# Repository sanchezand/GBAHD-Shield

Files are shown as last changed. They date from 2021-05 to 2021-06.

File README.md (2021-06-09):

# gbaHD Shield
This is a shield for the [gbaHD project](https://github.com/zwenergy/gbaHD).  

Has the following features.
- Connects via female headers to the Edge board (shield)
- Has a FFC 40, 32 and 34 pin connector for GBA LCD connector.
- Has a FFC 20 pin connector for controls with a wire up board.
- Has a ATMEGA328p for using a SNES Classic connector to control the GBA.
- **Both FFC cables need to be opposite side**

## Issues
- Havent had the chance to fully test the controller extension board, but the controller port on it works.
- Controller extension board needs to be made bigger and separate the button from the LED and the LED from the controller port.
- No case made for it yet
- GND pin on the breakout board needs to be moved (doesnt affect anything)
- Labels on breakout board need to be made bigger

## Contributing
If you wish to contribute, see something wrong or want to add a feature please make a pull request or leave an issue!

## BOM
|Reference	|Value								|
|---	|---							|
|C1, C2		|22pF									|
|C3			|100nF								|
|R1			|10K ohm									|
|R2			|120 ohm (or change for your LED)	|
|D1			|5mm LED or<br />TJ-L5FPTGCRMFCSFLC2R-A5	|
|U2			|ATMEGA328p-AU						|
|X1			|16MHz Crystal SMD-3225			|
|SW1			|XKB-TS-1185EC-C-D-B				|
|SW2			|XKB_XKB5858-Z-C					|
|J1			|JUSHUO_AFC01-S40FCC-00			|
|J2			|PinHeader 2x08 2.54mm			|
|J3, J9		|JUSHUO_AFC01-S20FCC-00			|
|J5			|JUSHUO_AFC07-S34FCC-00			|
|J7			|JUSHUO_AFC01-S32FCC-00			|
|J4			|PinHeader 2x10 2.54mm			|
|P1, P2		|Wii Expansion Port				|
|EXTRA 1		|PinHeader 1x08 2.54mm			|
|EXTRA 2		|PinHeader 1x06 2.54mm			|

## Programming the MCU
In order to program the MCU, you need an arduino to use as ISP.  
Use the following image to wire up an arduino to the board to program it.  
**I would also recomend not programming it while seated in the FPGA board.**
PCB Wireup  
After wiring the board, follow this tutorial to flash the bootloader and the sketch to the board.  
[ICSP Tutorial](https://www.arduino.cc/en/pmwiki.php?n=Tutorial/ArduinoISP)  
  
The Arduino code requires the [NintendoExtensionCtrl](https://github.com/dmadison/NintendoExtensionCtrl) library.

## Version 1 vs Version 2
- __Removed SNES connector for an classic controller connector__
- Made the PCB bigger and uses lower pins to improve stability
- Added future proof pins to the edge board.
- Panelized the board to lower the amount of PCBs needed
- Added an "Expansion" board to relocate the controller port and add an LED and power switch (which needs to desolder old switch and be wired to the Spartan board)
- Made the breakout board bigger and added more extra pins.
- Changed FFC connectors (except 34 pin) to use a clamp down connector.

## Images
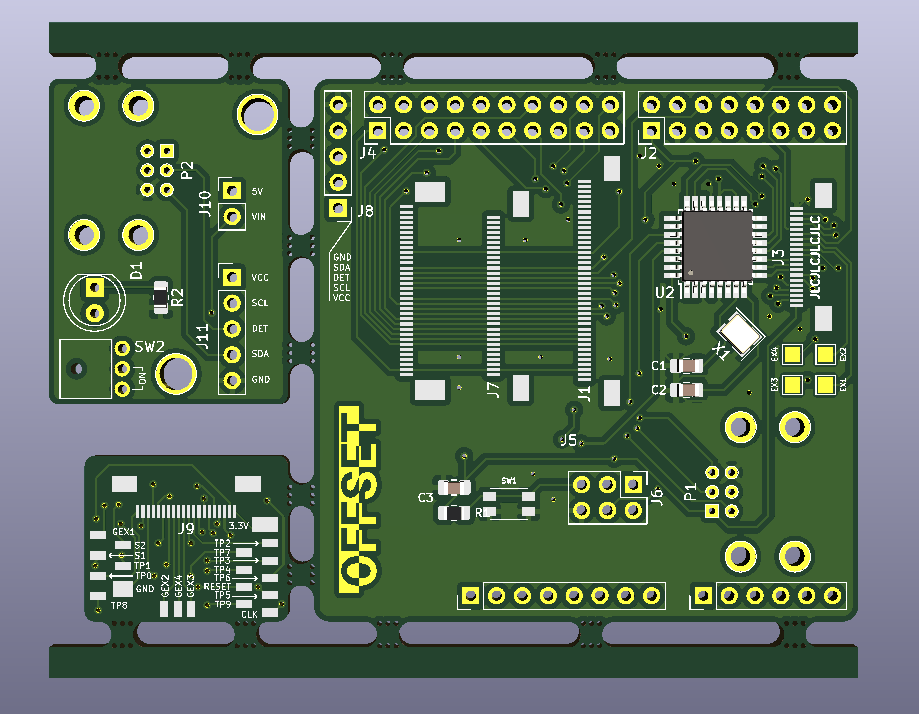
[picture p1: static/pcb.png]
PCB


## LICENSE
This documentation describes Open Hardware and is licensed under the CERN OHL v. 1.2.
You may redistribute and modify this documentation under the terms of the CERN OHL v.1.2. (http://ohwr.org/cernohl). This documentation is distributed WITHOUT ANY EXPRESS OR IMPLIED WARRANTY, INCLUDING OF MERCHANTABILITY, SATISFACTORY QUALITY AND FITNESS FOR A PARTICULAR PURPOSE. Please see the CERN OHL v.1.2 for applicable conditions.

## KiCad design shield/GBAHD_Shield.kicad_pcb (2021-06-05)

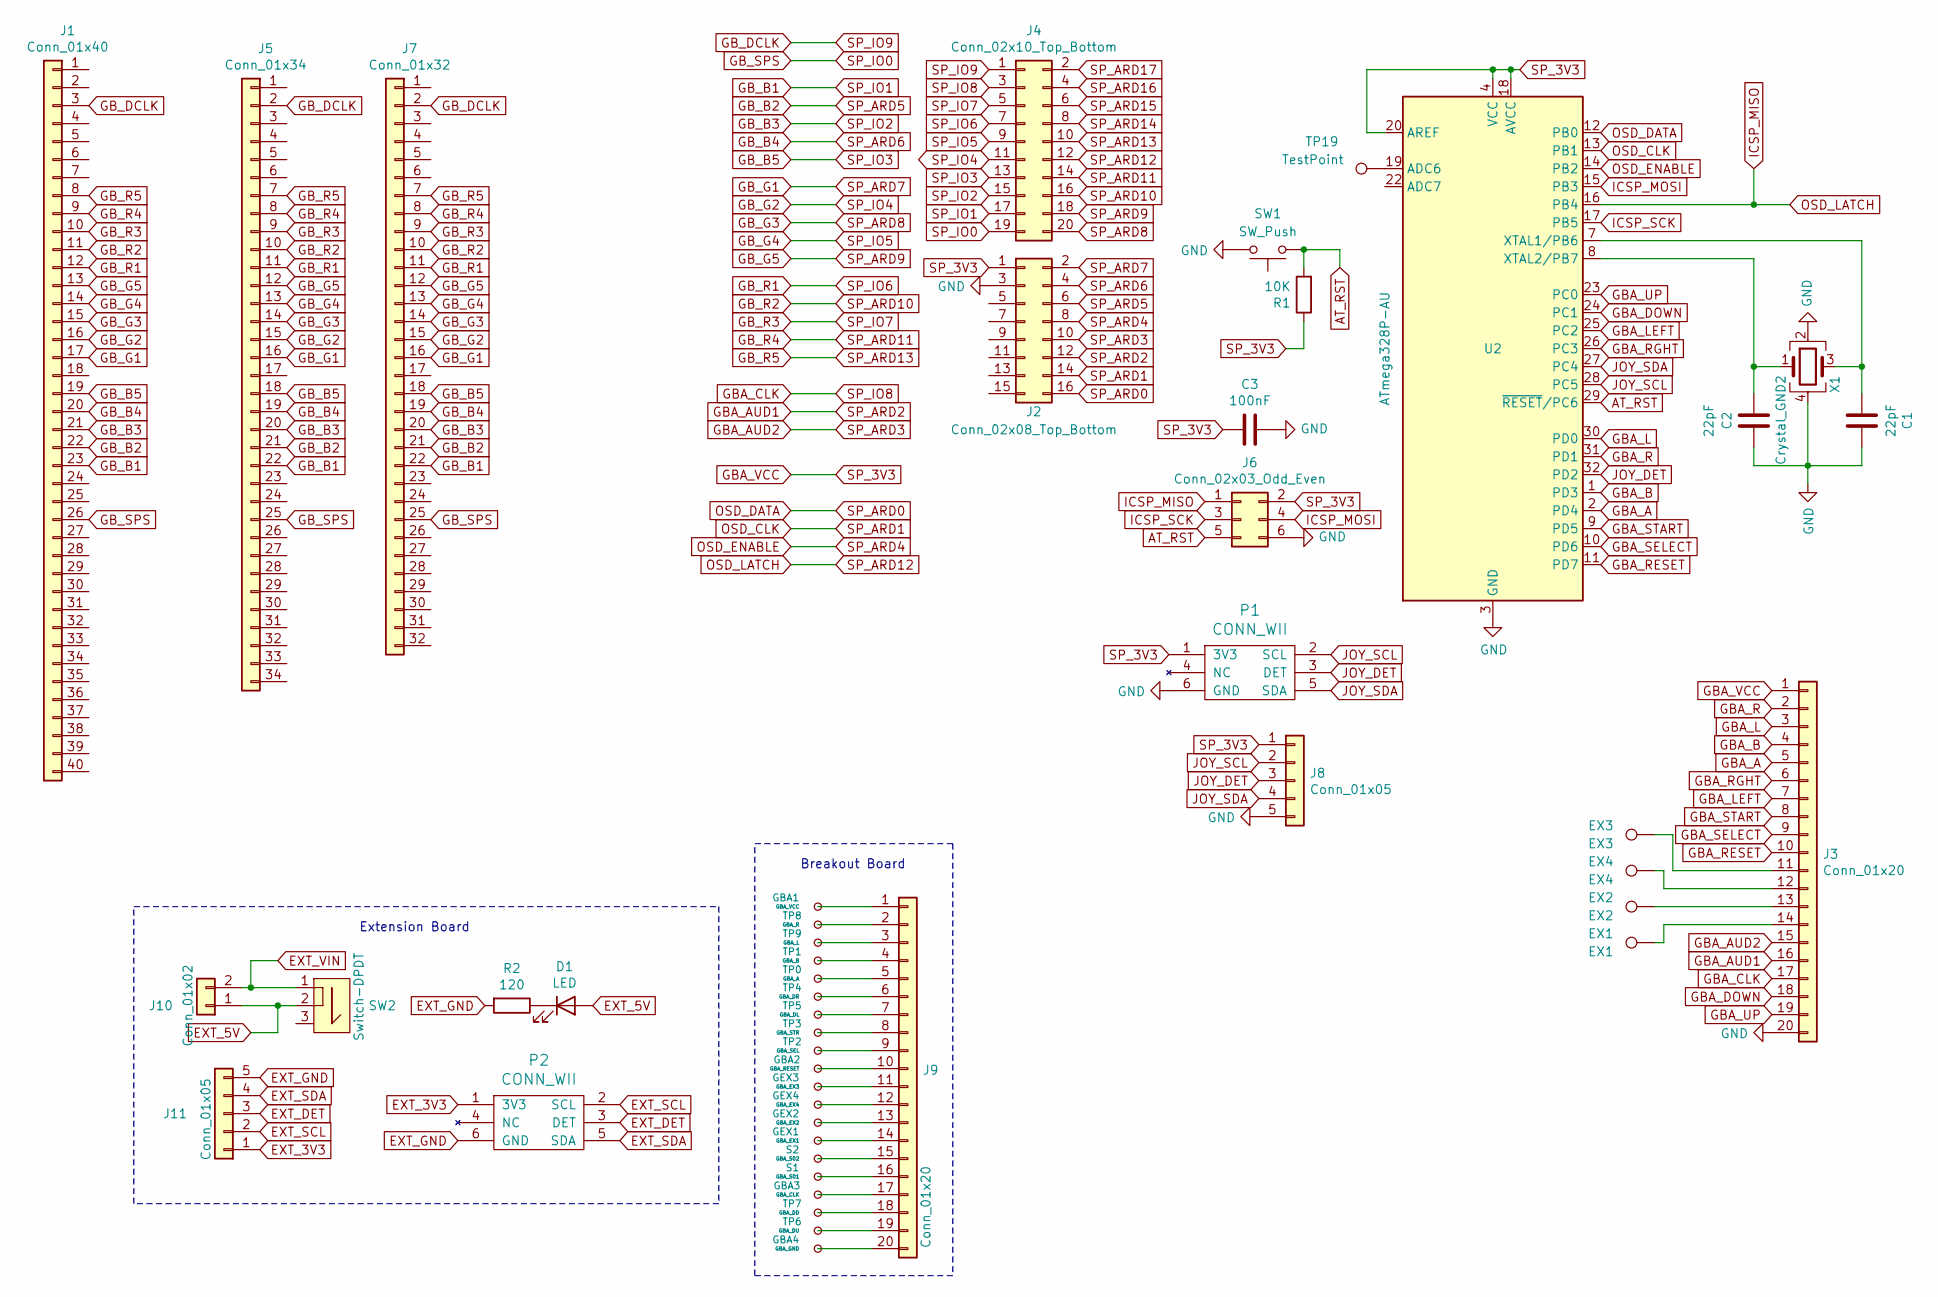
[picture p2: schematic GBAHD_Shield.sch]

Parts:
C1, C2: 22pF; C_0805_2012Metric_Pad1.18x1.45mm_HandSolder
C3: 100nF; C_0805_2012Metric_Pad1.18x1.45mm_HandSolder
D1: LED; LED_D5.0mm_FlatTop
EX1: EX1; SOLDER_PAD
EX2: EX2; SOLDER_PAD
EX3: EX3; SOLDER_PAD
EX4: EX4; SOLDER_PAD
GBA1: GBA_VCC; SOLDER_PAD
GBA2: GBA_RESET; SOLDER_PAD
GBA3: GBA_CLK; SOLDER_PAD
GBA4: GBA_GND; SOLDER_PAD
GEX1: GBA_EX1; SOLDER_PAD
GEX2: GBA_EX2; SOLDER_PAD
GEX3: GBA_EX3; SOLDER_PAD
GEX4: GBA_EX4; SOLDER_PAD
J1: Conn_01x40; JUSHUO_AFC01-S40FCC-00
J2: Conn_02x08_Top_Bottom; PinHeader_2x08_P2.54mm_Vertical
J3, J9: Conn_01x20; JUSHUO_AFC01-S20FCC-00
J4: Conn_02x10_Top_Bottom; PinHeader_2x10_P2.54mm_Vertical
J5: Conn_01x34; JUSHUO_AFC07-S34FCC-00
J6: Conn_02x03_Odd_Even; PinHeader_2x03_P2.54mm_Vertical
J7: Conn_01x32; JUSHUO_AFC01-S32FCC-00
J8, J11: Conn_01x05; PinHeader_1x05_P2.54mm_Horizontal
J10: Conn_01x02; PinHeader_1x02_P2.54mm_Horizontal
P1, P2: CONN_WII
R1: 10K; R_0805_2012Metric_Pad1.20x1.40mm_HandSolder
R2: 120; R_0805_2012Metric_Pad1.20x1.40mm_HandSolder
S1: GBA_S01; SOLDER_PAD
S2: GBA_S02; SOLDER_PAD
SW1: SW_Push; XKB-TS-1185EC-C-D-B
SW2: Switch-DPDT; XKB_XKB5858-Z-C
TP0: GBA_A; SOLDER_PAD
TP1: GBA_B; SOLDER_PAD
TP2: GBA_SEL; SOLDER_PAD
TP3: GBA_STR; SOLDER_PAD
TP4: GBA_DR; SOLDER_PAD
TP5: GBA_DL; SOLDER_PAD
TP6: GBA_DU; SOLDER_PAD
TP7: GBA_DD; SOLDER_PAD
TP8: GBA_R; SOLDER_PAD
TP9: GBA_L; SOLDER_PAD
TP19: TestPoint; SOLDER_PAD
U2: ATmega328P-AU; TQFP-32_7x7mm_P0.8mm
X1: Crystal_GND2; Crystal_SMD_3225-4Pin_3.2x2.5mm

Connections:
AT_RST: J6.5, R1.2, SW1.1, U2.29 (~RESET~/PC6)
EXT_3V3: J11.1, P2.1 (3V3)
EXT_5V: D1.2 (A), J10.1, SW2.2
EXT_DET: J11.3, P2.3 (DET)
EXT_GND: J11.5, P2.6 (GND), R2.2
EXT_SCL: J11.2, P2.2 (SCL)
EXT_SDA: J11.4, P2.5 (SDA)
EXT_VIN: J10.2, SW2.1
GBA_A: J3.5, U2.2 (PD4)
GBA_AUD1: J2.12, J3.16
GBA_AUD2: J2.10, J3.15
GBA_B: J3.4, U2.1 (PD3)
GBA_CLK: J3.17, J4.3
GBA_DOWN: J3.18, U2.24 (PC1)
GBA_L: J3.3, U2.30 (PD0)
GBA_LEFT: J3.7, U2.25 (PC2)
GBA_R: J3.2, U2.31 (PD1)
GBA_RESET: J3.10, U2.11 (PD7)
GBA_RGHT: J3.6, U2.26 (PC3)
GBA_SELECT: J3.9, U2.10 (PD6)
GBA_START: J3.8, U2.9 (PD5)
GBA_UP: J3.19, U2.23 (PC0)
GBA_VCC: C3.2, J2.1, J3.1, J6.2, J8.1, P1.1 (3V3), R1.1, U2.4 (VCC), U2.6 (VCC), U2.18 (AVCC), U2.20 (AREF)
GB_B1: J1.23, J4.17, J5.22, J7.22
GB_B2: J1.22, J2.6, J5.21, J7.21
GB_B3: J1.21, J4.15, J5.20, J7.20
GB_B4: J1.20, J2.4, J5.19, J7.19
GB_B5: J1.19, J4.13, J5.18, J7.18
GB_DCLK: J1.3, J4.1, J5.2, J7.2
GB_G1: J1.17, J2.2, J5.16, J7.16
GB_G2: J1.16, J4.11, J5.15, J7.15
GB_G3: J1.15, J4.20, J5.14, J7.14
GB_G4: J1.14, J4.9, J5.13, J7.13
GB_G5: J1.13, J4.18, J5.12, J7.12
GB_R1: J1.12, J4.7, J5.11, J7.11
GB_R2: J1.11, J4.16, J5.10, J7.10
GB_R3: J1.10, J4.5, J5.9, J7.9
GB_R4: J1.9, J4.14, J5.8, J7.8
GB_R5: J1.8, J4.10, J5.7, J7.7
GB_SPS: J1.26, J4.19, J5.25, J7.25
GND: C1.1, C2.1, C3.1, J2.3, J3.20, J6.6, J8.5, P1.6 (GND), SW1.2, U2.3 (GND), U2.5 (GND), U2.21 (GND), X1.2, X1.4
ICSP_MISO: J4.12, J6.1, U2.16 (PB4)
ICSP_MOSI: J6.4, U2.15 (PB3)
ICSP_SCK: J6.3, U2.17 (PB5)
JOY_DET: J8.3, P1.3 (DET), U2.32 (PD2)
JOY_SCL: J8.2, P1.2 (SCL), U2.28 (PC5)
JOY_SDA: J8.4, P1.5 (SDA), U2.27 (PC4)
unnamed: C1.2, U2.7 (XTAL1/PB6), X1.3
unnamed: C2.2, U2.8 (XTAL2/PB7), X1.1
unnamed: D1.1 (K), R2.1
unnamed: EX1.1, J3.14
unnamed: EX2.1, J3.13
unnamed: EX3.1, J3.11
unnamed: EX4.1, J3.12
unnamed: GBA1.1, J9.1
unnamed: GBA2.1, J9.10
unnamed: GBA3.1, J9.17
unnamed: GBA4.1, J9.20
unnamed: GEX1.1, J9.14
unnamed: GEX2.1, J9.13
unnamed: GEX3.1, J9.11
unnamed: GEX4.1, J9.12
unnamed: J9.2, TP8.1
unnamed: J9.3, TP9.1
unnamed: J9.4, TP1.1
unnamed: J9.5, TP0.1
unnamed: J9.6, TP4.1
unnamed: J9.7, TP5.1
unnamed: J9.8, TP3.1
unnamed: J9.9, TP2.1
unnamed: J9.15, S2.1
unnamed: J9.16, S1.1
unnamed: J9.18, TP7.1
unnamed: J9.19, TP6.1
unnamed: TP19.1, U2.19 (ADC6)
OSD_CLK: J2.14, U2.13 (PB1)
OSD_DATA: J2.16, U2.12 (PB0)
OSD_ENABLE: J2.8, U2.14 (PB2)
SP_ARD14: J4.8
SP_ARD15: J4.6
SP_ARD16: J4.4
SP_ARD17: J4.2

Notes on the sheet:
Breakout Board
Extension Board

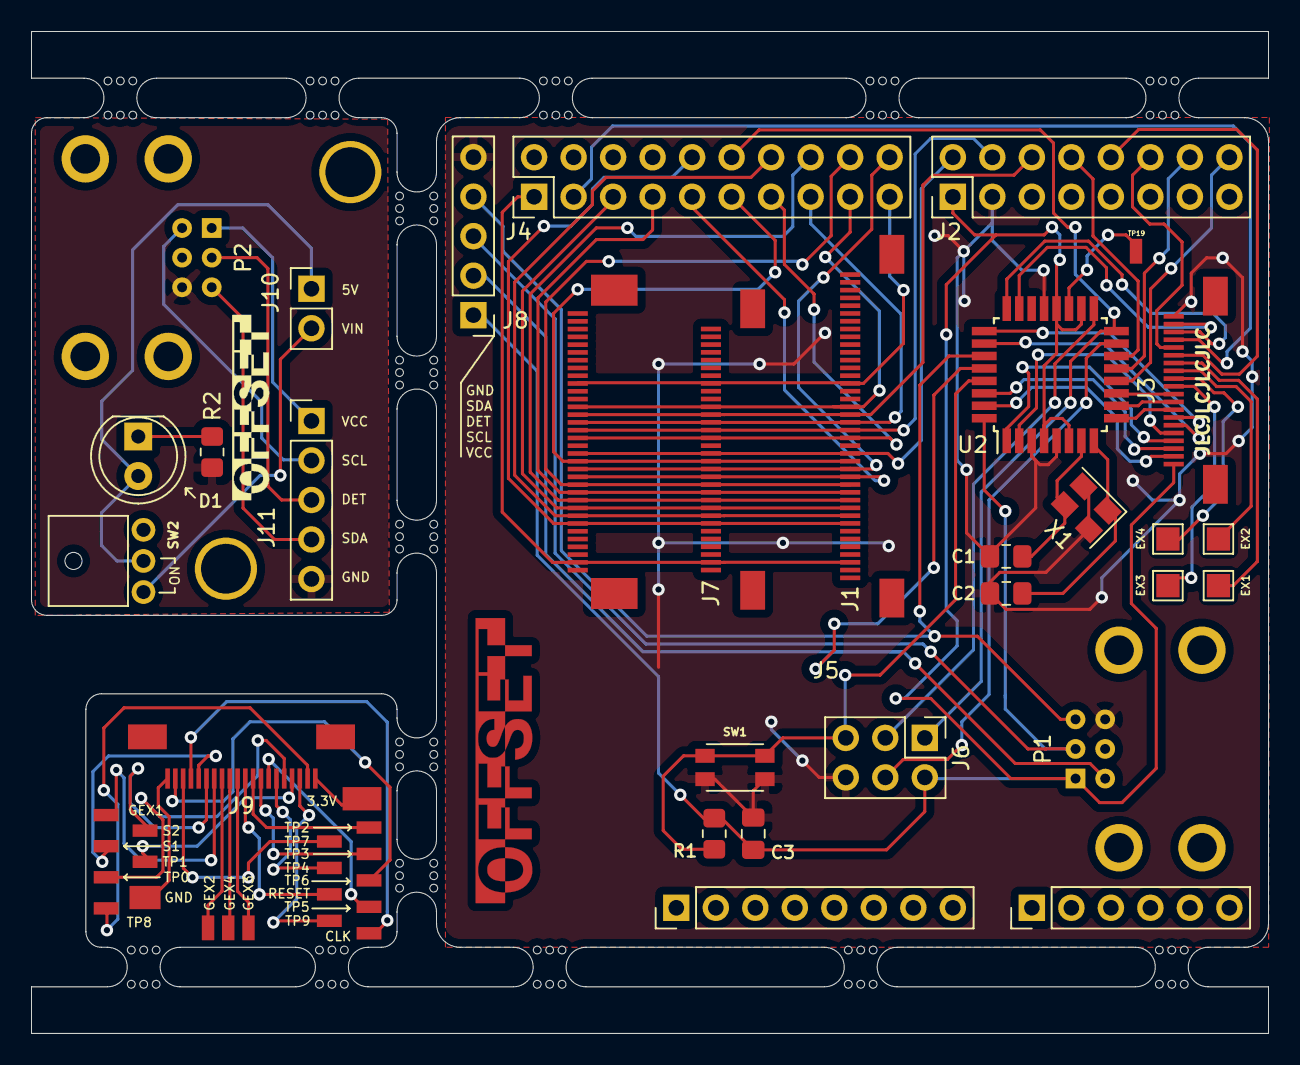
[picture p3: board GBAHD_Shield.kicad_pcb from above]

Board: 2 copper layers, 79.5 x 64.4 mm, 67 parts (0 on the bottom side), 78 nets.

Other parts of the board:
EXP1: PinHeader_1x08_P2.54mm_Vertical
EXP2: PinHeader_1x06_P2.54mm_Vertical
HOLEM3, HOLEM3#2: VAL**; HOLE_M3
mousebite: VAL**; mouse-bite-2.54mm-slot
mousebite#2, mousebite#3, mousebite#4, mousebite#5, mousebite#6, mousebite#7, mousebite#8, mousebite#9, mousebite#10, mousebite#11, mousebite#12, mousebite#13, mousebite#14, mousebite#15: VAL**; mouse-bite-2.54mm-slot

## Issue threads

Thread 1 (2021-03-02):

Programming the chip is not possible when fully assembled

kinoX51, 2021-03-02:
I've ordered pcbs and parts, soldered everything together and tried to program the atmega328 with a arduino nano after the tutorial on the arduino.cc-website.
When I try to burn the bootloader I get an error

avrdude: Device signature = 0xffffff (probably .avr8x_mega)
avrdude: Yikes!  Invalid device signature.
         Double check connections and try again, or use -F to override
         this check.

I've checked the wiring, and double checked my components - even when only the atmega is on the board I'll get the error message.

I've tried to switch the atmega for a 328pb, but still not luck.

I've used this crystal (https://lcsc.com/product-detail/SMD-Crystal-Resonators_XTY-7325-0800A2010-00_C389817.html) with the 22pf-caps, since there is no part number for a specific one.

Is there a special procedure what to solder first to get the bootloader on the atmega?

I have about 20 pcbs and parts here - would be nice to get them programmed.

Thanks!

kinoX51

sanchezand, 2021-03-02:
I had problems programming the chip with 8MHz too, I am no expert at bootloader burning but I the issue is the bootloader is made for 16MHz crystals. There are bootloaders for 8MHz crystals but that requires changing arduino board definitions.

I had some 16MHz crystals with the same footprint around and that worked flawlessly. I forgot to change the BOM to 16MHz for an easier bootloader burning and more Ardunio IDE compability, but I changed it now.

kinoX51, 2021-03-02:
OK, I'll try a 16MHz crystal - is it possible to get an lcsc part number for that?
What Arduino are you using to program the ATMEGA?

sanchezand, 2021-03-02:
This one should work:
https://lcsc.com/product-detail/SMD-Crystal-Resonators_Seiko-Epson-X1E000021037500_C89379.html

I used an Arduino nano to program the board.
Sorry for the confusion!

kinoX51, 2021-03-02:
thanks for you help - I'll try that - arduino nano - old wiring-style or default-arduino-isp sketch?

kinoX51, 2021-03-05:
I've made some progress.
After a lot of reading I was able to burn the bootloader onto the board with an 8MHz crystal - I've just needed to use MiniCore und slowing down the Baud-Rate zu 19200 when uploading the bootloader.

Nice to know: Since the board isn't providing a UART-Header the bootloader isn't even needed. It's possible to upload the sketch directly over the iscp header without having to upload the bootloader first.

I'm also able to upload the sketch using the programmer - but now I have another problem.
When uploading the sketch to the atmega Pin 11 should be in a high state to switch on the power delivery on the WAS3157B
When measuring the voltage on the output pin it only shows abount 0.8v not enough to power the gba.

When I close the jumper SJ1 the GBA turns on but no button presses are registered on the gba side.

Is the firmware the last revision?

Thanks!

ManCloud, 2021-03-21:
This issue might be related to the fact, that the gerber files have a failure: the pin mapping for the Reset Button is wrong.

Therefore the microcontroller is held in reset statel.

To bypass this issue you can cut the pins of the button diagonally or simply dismount the button completely.

This should fix your problem ^^

sanchezand, 2021-03-22:
Yes the gerbers are outdated and the issue was fixed on a later commit. I also ordered the pcb with the issue and soldered the button vertically but removing the button should work.
As for the analog switch issue I had some problems powering the GBA from the ICSP headers. Try powering the shield mounted in the Spartan Edge.
To debug the no button presses check for continuity from the gba test pads to the MCU and check the breakout's wiring

ManCloud, 2021-03-22:
The analog-switch solution is not so good.
According to the datasheet it has an internal resistance of 5.5 Ohm.

This lead to a voltage drop of approx. 0.4V @ 75mA (highest current I've measured on my GBA SP Board in operation without display).

On a OGBA board this would mean a voltage of 2.9V.

A high side switch with a mosfet is more suitable in my opinion.

Especially because there is only one "channel" used of the analog Switch.

kinoX51, 2021-03-22:
Ordering the board with the KiCad-Files lead to a working board with the switch mounted.
With the help from ManCloud I was able to program the Atmega even with the 8MHz crystal - when i remember correctly 16MHz on 3.3v is not recommended as you overclock the Atmega and run it out of spec.
To program the Atmega you don't need to upload the bootloader.
Uploading the code using the programer is all that it takes.
I've used the Minicore library in ARDUINO IDE to set the correct values (8MHz, external crystal etc.) and lowered the BAUD-Rate to 19200 in the Minicore boards.txt-file.

After that the board worked but I had issues to get the GBA running stable with an Everdrive or normal cartridge.
This is due to the Analog Switch ICs voltage drop as ManCloud has pointed out.
If you let the Analog Switch IC unpopulated and short SJ1 the GBA works perfectly without the IGR.

sanchezand, 2021-05-24:
I never had issue with the analog switch restarting the GBA nor it not giving it enough current to the GBA, although I guess the GBA's condition could be at fault if that happens. In the new version I've removed the switch and its now using the GBA's reset pin.

Also the new version's BOM uses a 16MHz to avoid any problems flashing the firmware

Closed 2021-05-24.

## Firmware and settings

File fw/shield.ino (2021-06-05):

#include <NintendoExtensionCtrl.h>

#define OSD_LATCH 12   // PIN 16
#define OSD_CLOCK 9     // PIN 13
#define OSD_DATA 8    // PIN 12
#define OSD_TOGGLE 10   // PIN 14

#define GB_A      4
#define GB_B      3
#define GB_UP     14
#define GB_DOWN   15
#define GB_LEFT   16
#define GB_RIGHT  17
#define GB_L      0
#define GB_R      1
#define GB_START  5
#define GB_SELECT 6

int btn_pins[12] = {
  GB_B, 99, GB_SELECT, GB_START, GB_UP, GB_DOWN, GB_LEFT, GB_RIGHT, GB_A, 99, GB_L, GB_R
};

bool osd_toggle = false;
bool osd_toggled = false;

SNESMiniController snes;

void setup() {
  pinMode(OSD_CLOCK, OUTPUT);
  pinMode(OSD_DATA, OUTPUT);
  pinMode(OSD_TOGGLE, OUTPUT);
  pinMode(OSD_LATCH, OUTPUT);

  digitalWrite(OSD_CLOCK, LOW);
  digitalWrite(OSD_DATA, LOW);
  digitalWrite(OSD_LATCH, LOW);
  digitalWrite(OSD_TOGGLE, osd_toggle);

  for(int i=0; i<12; i++){
    if(btn_pins[i] == 99) continue;
    pinMode(btn_pins[i], OUTPUT);
    digitalWrite(btn_pins[i], 1);
  }

  snes.begin();

  while (!snes.connect()) {
    delay(1000);
  }
}

// PAYLOAD => UP, DOWN, LEFT, RIGHT, A, B
bool payload[6] = {0,0,0,0,0,0};
bool old_payload[6] = {0,0,0,0,0,0};
bool controller_payload[12] = {0,0,0,0,0,0,0,0,0,0,0,0};
int test = 0;

bool payloadChange(){
  for(int i=0; i<6; i++){
    if(payload[i]!=old_payload[i]) return true;
  }
  return false;
}

void outputOSD(){
  digitalWrite(OSD_LATCH, HIGH);
  delayMicroseconds(1 );
  digitalWrite(OSD_LATCH, LOW);
  for(int i=0; i<6; i++){
    delayMicroseconds(1);
    digitalWrite(OSD_DATA, payload[i]);
    digitalWrite(OSD_CLOCK, HIGH);
    delayMicroseconds(1);
    digitalWrite(OSD_CLOCK, LOW);
    old_payload[i] = payload[i];
  }
  digitalWrite(OSD_DATA, LOW);
}

void outputGBA(){
  for(int i=0; i<12; i++){
    if(btn_pins[i] == 99) continue;
    digitalWrite(btn_pins[i], !controller_payload[i]);
  }
}

void readController(){
  boolean success = snes.update();
  if(!success){
    for(int i=0; i<6; i++){
      payload[i] = 0;
    }
  }
  controller_payload[0] = snes.buttonB();
  controller_payload[1] = snes.buttonY();
  controller_payload[2] = snes.buttonSelect();
  controller_payload[3] = snes.buttonStart() && (!snes.buttonL() && !snes.buttonR());
  controller_payload[4] = snes.dpadUp();
  controller_payload[5] = snes.dpadDown();
  controller_payload[6] = snes.dpadLeft();
  controller_payload[7] = snes.dpadRight();
  controller_payload[8] = snes.buttonA();
  controller_payload[9] = snes.buttonX();
  controller_payload[10] = snes.buttonL();
  controller_payload[11] = snes.buttonR();

  payload[0] = controller_payload[0];
  payload[1] = controller_payload[8];
  payload[2] = controller_payload[7];
  payload[3] = controller_payload[6];
  payload[4] = controller_payload[5];
  payload[5] = controller_payload[4];

  if(snes.buttonL() && snes.buttonR() && snes.buttonStart()){
    if(!osd_toggled){
      osd_toggle = !osd_toggle;
      digitalWrite(OSD_TOGGLE, osd_toggle);
      osd_toggled = true;
    }
  }else{
    osd_toggled = false;
  }
}

void loop() {
  readController();
  if(osd_toggle){
    outputOSD(); 
  }else{
    outputGBA();
  }
}

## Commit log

2021-05-15 Version 2 initial commit.
    - Changed board layout
    - Changed breakout board pin order
    - Changed FFC connectors
    - Added connectors for 32 pin and 34 pin
    - Changed SNES connector to Classic connector.
    [GBAHD_Shield-B_Cu.gbr, GBAHD_Shield-B_Mask.gbr, GBAHD_Shield-B_Paste.gbr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]
2021-05-16 PCB changes and breakout board
    - Added breakout to main board as a breakaway board.
    - Added controller connector expansion for port relocation
    - Tidying routing and other minimal changes
    [GBAHD_Shield.kicad_pcb, GBAHD_Shield.sch]
2021-05-16 PCB design work
    - Added extension board (controller, LED and power switch)
    - Panelized board
    [GBAHD_Shield.kicad_pcb, GBAHD_Shield.sch]
2021-05-16 Removed old breakout PCB
    [GBABreakout-B_Cu.gbr, GBABreakout-B_Mask.gbr, GBABreakout-B_Paste.gbr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]
2021-05-17 Added BOM, minor fixes
    [GBAHD_Shield.kicad_pcb]
2021-05-17 Minor PCB changes
    [GBAHD_Shield.kicad_pcb]
2021-06-04 Updated v2 shield arduino sketch.
2021-06-04 Updated board files to include new trace.
    [GBAHD_Shield.sch]
2021-06-05 Fixed moved traces
    [GBAHD_Shield.kicad_pcb]
